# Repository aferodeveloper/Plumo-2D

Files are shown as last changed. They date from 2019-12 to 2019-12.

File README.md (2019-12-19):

# Plumo-2D Feather/FeatherWing compatible Development Board for the Afero Platform

## INTRODUCTION

Plumo-2D is a development board for the Afero ASR-2D Secure WiFi/BLE radio architecture based on the ESP32 WiFi/BLE chipset.  Plumo-2D is compatible with Adafruit Feather/FeatherWing form factor boards.

This reference design is meant for customers to use for product prototyping and as a starting point for their own designs.  The Plumo-2D uses the Espressif ESP32-WROOM-32D module + the Afero Hardware Security Module.  Use of the pre-certified Espressif ESP32-WROOM-32D module gives the board FCC/IC, TELEC, and other certifications.

For more information, please see the Afero developer site: https://developer.afero.io

## Design Information
The Plumo-2D design was built using Altium.  The entire Altium project, including scripts that generate the output files, is included.

## Manifest (abridged)
 * **Plumo-2D.PrjPcb** is the toplevel Altium project file.
 * **Plumo-2D.SchDoc** is the Altium schematic file.
 * **Plumo-2D.PcbDoc** is the Altium layout file.
 * **Plumo-2D.IntLib** is an integrated Altium part library for the design.
 * **AssyDrawing.PCBDwf** and **FabDrawing.PCBDwf** are drawing templates for the Assembly and Fabrication drawings.
 * **documentation.OutJob** and **gerbers.OutJob** are the "scripts" for Altium that you can use to generate all of the needed output files (pdf files, gerbers, pick and place info, et cetera).
 * **Plumo-2D.pdf** pdf of the schematics, isometric view of the board, fab and assembly drawings; autogenerated.
 * **gerbers** is the directory where the Gerber output files and ODB++ files are located.  These are the files that one would use when you release the board to fab and assembly; autogenerated.
 * **gerbers/Bill of Materials-Plumo-2D.csv** is the Bill of Materials for the debug version of the board; autogenerated.
 * **LICENSE.txt** Apache 2.0 license governing the use of this design.
 * **NOTICE** Copyright information.
 * **README.md** This file.

Please note that the Afero Secure Radio firmware stack and hardware security modules used in the design are not publicly available.  Please contact Afero about licensing these items.

## CONTRIBUTORS
Original design by Afero, Inc.

Copyright 2018, 2019 Afero, Inc.

Licensed under the Apache 2.0 license; check LICENSE.txt for more information.  All text above must be included in any redistribution.

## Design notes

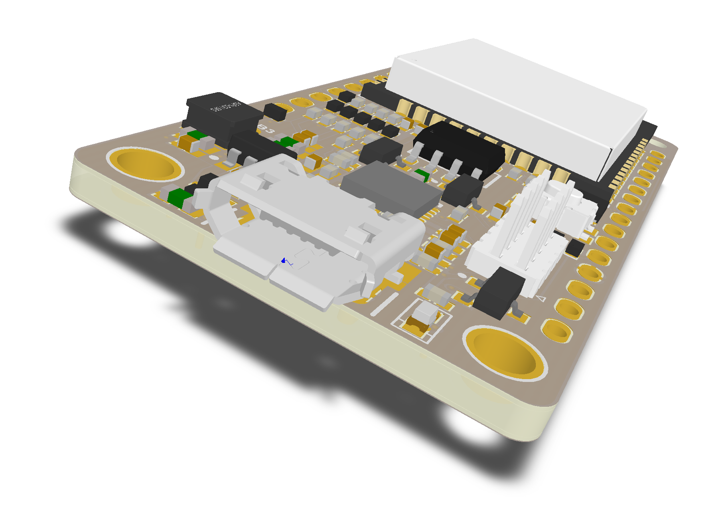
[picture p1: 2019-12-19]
Plumo2D_Iso-view.png

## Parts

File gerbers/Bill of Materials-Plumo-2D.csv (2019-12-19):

item_number | Comment | Quantity | Designator | Description | Manufacturer | Manufacturer Part Number
E-CAP-00090-00 | 100nF | 7 | C1, C3, C10, C11, C13, C15, C17 | Capacitor 100nF X5R 50V 10% 0402 | Murata | GRM155R61H104KE19D
E-CAP-00110-00 | 18pF | 2 | C2, C4 | Capacitor, 18pF, 50V, 1%, C0G | Murata | GJM1555C1H180FB01D
E-CAP-00020-00 | 1uF | 5 | C5, C12, C14, C16, C20 | Capacitor 1uF X5R 6.3V 20% 0402 | SEM | CL05A105KQ5NNNC
E-CAP-00100-00 | 10uF | 2 | C6, C7 | Capacitor 10uF X5R 16V 20% 0603 | Murata | GRM188R61C106MA73D
E-CAP-00107-00 | 20pF | 1 | C8 | Capacitor 20pF C0G 50V 1% 0402 | Murata | GJM1555C1H200FB01D
E-CAP-00108-00 | 2.2uF | 1 | C9 | Capacitor 2.2uF X5R 25V 10% 0603 | Murata | GRM188R61E225KA12D
E-CAP-00066-00 | 4.7uF | 2 | C18, C19 | Capacitor 4.7uF X5R 10V 10% 0603 | Taiyo Yuden | LMK107BJ475KA-T
E-DIO-00011-00 | SP3118-01ETG | 1 | D1 | Diode TVS | Littelfuse | SP3118-01ETG
E-DIO-00008-00 | TPD1E05U06 | 11 | D2, D3, D6, D7, D8, D9, D11, D12, D13, D14, D15 | Diode TVS | Texas Instruments | TPD1E05U06DPYR
E-LED-00012-00 | Orange | 1 | D4 | LED Orange 0603 | Vishay Lite-On | LTST-C190KAKT
E-DIO-00012-00 | NSR05T30XV2T5G | 1 | D10 | Diode Schottky 30V 0.5A SOD523 | On Semiconductor | NSR05T30XV2T5G
M-CON-00086-00 | HDR-1x12 | 1 | J2 | 0.1 header 12 positions" | Molex | 22032121
M-CON-00087-00 | HDR-1x16 | 1 | J3 | 0.1 header 16 positions" | Molex | 22032161
M-CON-00016-00 | HDR-2x5 | 1 | J4 | .050 Male Header 2x5 |  | GRPB052VWVN-RC
M-CON-00011-00 | 10103594-0001LF | 1 | J5 | Connector MICRO USB B | Amphenol FCI | 10103594-0001LF
E-IND-00043-00 | 10uH | 1 | L1 | Inductor 10uH 1.1A 0.22ohm 20% 3x3 | Abracon | ASPI-0315FS-100M
E-ICS-00097-00 | ESP32-WROOM-32D | 1 | MOD1 | Module WIFI BLE ESP32-D0WD 4MB | Espressif | ESP32-WROOM-32D
E-TRS-00003-00 | 2N7002 | 1 | Q2 | TR MOSFET N-CH 60V 115mA SOT23 | On Semiconductor | 2N7002
E-TRS-00002-00 | MMBT3904 | 2 | Q3, Q4 | TR NPN BJT 200mA 40V | On Semiconductor | MMBT3904LT1G
E-RES-00008-00 | 100 | 6 | R6, R17, R18, R19, R20, R22 | Resistor 100R 50V 5% 0402 | Panasonic | ERJ-2GEJ101X
E-RES-00039-00 | 4.7k | 3 | R7, R8, R31 | Resistor 4.7K 50V 5% 0402 | Panasonic | ERJ-2GEJ472X
E-RES-00012-00 | 100k | 2 | R9, R10 | Resistor 100K 50V 5% 0402 | Panasonic | ERJ-2GEJ104X
E-RES-00001-00 | 10k | 4 | R12, R13, R28, R29 | Resistor 10K 50V 5% 0402 | Vishay Dale | CRCW040210K0JNED
E-RES-00054-00 | 200K | 2 | R15, R21 | Resistor 200K 50V 1% 0402 | Panasonic | ERJ-2RKF2003X
E-RES-00093-00 | 680k | 1 | R16 | Resistor 680K 50V 5% 0402 | Panasonic | ERJ-2GEJ684X
E-RES-00006-00 | 0 | 1 | R23 | Resistor 0R 50V 1% 0402 | Yageo | RC0402FR-070RL
E-RES-00002-00 | 1k | 3 | R25, R26, R27 | Resistor 1K 50V 5% 0402 | Panasonic | ERJ-2GEJ102X
E-SWI-00022 | KMR231NGLFS | 1 | S1 | SMD Tact Switch | ITT C&K | KMR231NGLFS
E-ICS-00099-00 | IPS6404L-SQ | 1 | U1 | Memory SPI/QPI PSRAM 8MB SOIC8 150mil | IPUS | IPS6404L-SQ-SPN
E-ICS-00072-00 | ATECC508A | 1 | U2 | Afero Custom CryptoAuthentication Device | Microchip / Atmel | ATECC508A-MAHKN-T
E-ICS-00096-00 | XC9264B755MR | 1 | U3 | Voltage Regulator 0.5A 500KHz Buck | Torex | XC9264B755MR
E-ICS-00098-00 | CP2104 | 1 | U4 | USB to UART Bridge | SiLabs | CP2104-F03-GM
E-XTL-00012-00 | 32.768KHz | 1 | X1 | Crystal, 32.768kHz ±20ppm | Abracon | ABS06-32.768KHZ-T

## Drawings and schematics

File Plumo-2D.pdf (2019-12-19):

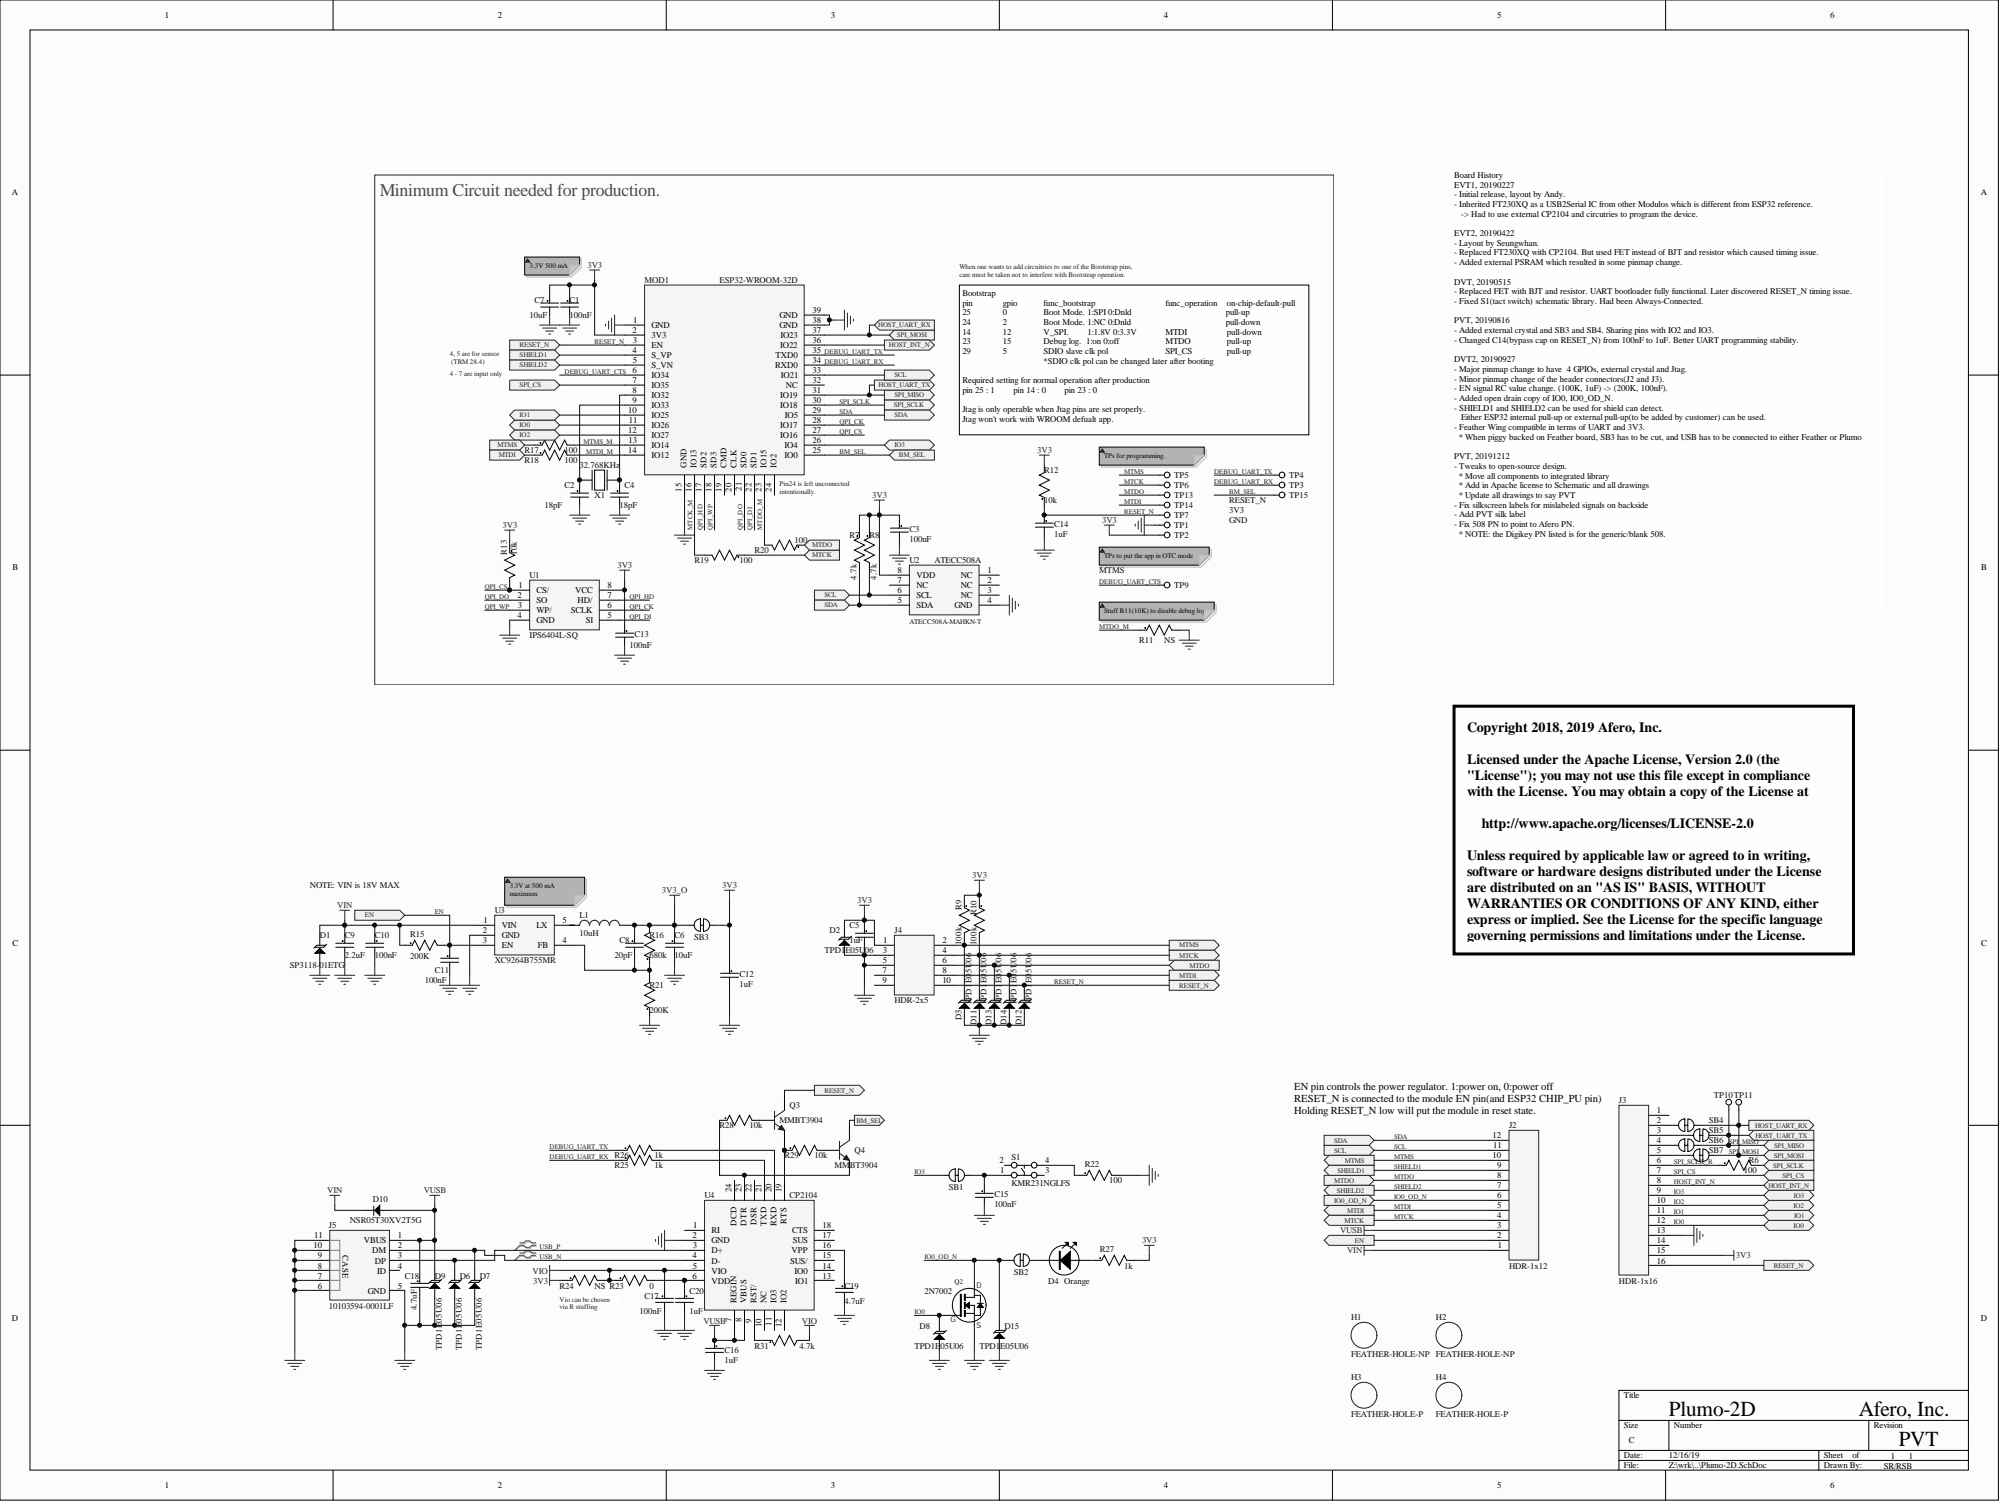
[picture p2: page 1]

Board History
EVT1, 20190227
- Initial release, layout by Andy.
- Inherited FT230XQ as a USB2Serial IC from other Modulos which is different from ESP32 reference.
-> Had to use external CP2104 and circutries to program the device.

Minimum Circuit needed for production.

EVT2, 20190422
- Layout by Seungwhan.
- Replaced FT230XQ with CP2104. But used FET instead of BJT and resistor which caused timing issue.
- Added external PSRAM which resulted in some pinmap change.

When one wants to add circuitries to one of the Bootstrap pins,
care must be taken not to interfere with Bootstrap operation.

DVT, 20190515
- Replaced FET with BJT and resistor. UART bootloader fully functional. Later discovered RESET_N timing issue.
- Fixed S1(tact switch) schematic library. Had been Always-Connected.

PVT, 20190816
- Added external crystal and SB3 and SB4. Sharing pins with IO2 and IO3.
- Changed C14(bypass cap on RESET_N) from 100nF to 1uF. Better UART programming stability.

*SDIO clk pol can be changed later after booting

DVT2, 20190927
- Major pinmap change to have 4 GPIOs, external crystal and Jtag.
- Minor pinmap change of the header connectors(J2 and J3).
- EN signal RC value change. (100K, 1uF) -> (200K, 100nF).
- Added open drain copy of IO0, IO0_OD_N.
- SHIELD1 and SHIELD2 can be used for shield can detect.
Either ESP32 internal pull-up or external pull-up(to be added by customer) can be used.
- Feather Wing compatible in terms of UART and 3V3.
* When piggy backed on Feather board, SB3 has to be cut, and USB has to be connected to either Feather or Plumo

Required setting for normal operation after production

IO25 10
IO26 11
IO27 12 | QPI_CS

Jtag is only operable when Jtag pins are set properly.
Jtag won't work with WROOM defualt app.

MTMS_M | IO14 13 | BM_SEL
MTDI_M | IO12 14
32.768KHz

PVT, 20191212
- Tweaks to open-source design.
* Move all components to integrated library
* Add in Apache license to Schematic and all drawings
* Update all drawings to say PVT
- Fix silkscreen labels for mislabeled signals on backside
- Add PVT silk label
- Fix 508 PN to point to Afero PN.
* NOTE: the Digikey PN listed is for the generic/blank 508.

TPs to put the app in OTC mode
MTMS
DEBUG_UART_CTS

Stuff R11(10K) to disable debug log

Licensed under the Apache License, Version 2.0 (the
"License"); you may not use this file except in compliance
with the License. You may obtain a copy of the License at

http://www.apache.org/licenses/LICENSE-2.0

Unless required by applicable law or agreed to in writing,
software or hardware designs distributed under the License
are distributed on an "AS IS" BASIS, WITHOUT
WARRANTIES OR CONDITIONS OF ANY KIND, either
express or implied. See the License for the specific language
governing permissions and limitations under the License.

NOTE: VIN is 18V MAX

EN pin controls the power regulator. 1:power on, 0:power off
RESET_N is connected to the module EN pin(and ESP32 CHIP_PU pin)
Holding RESET_N low will put the module in reset state.

Vio can be chosen
via R stuffing

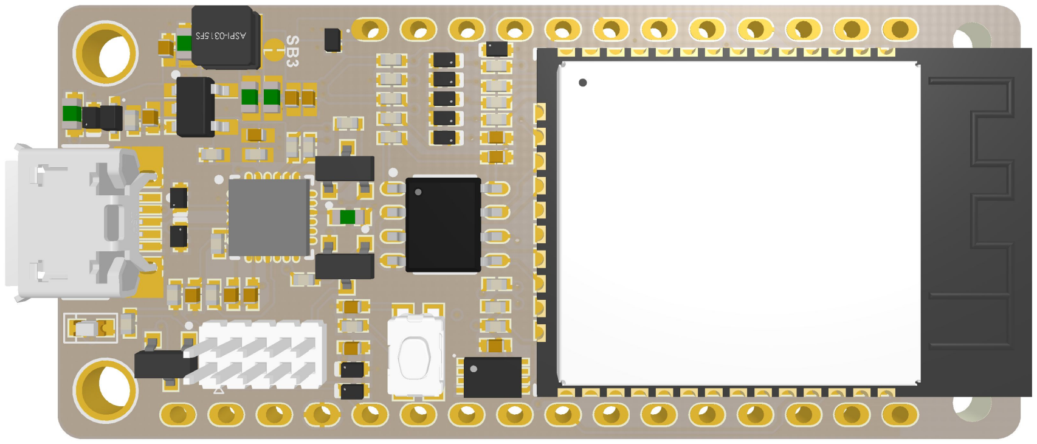
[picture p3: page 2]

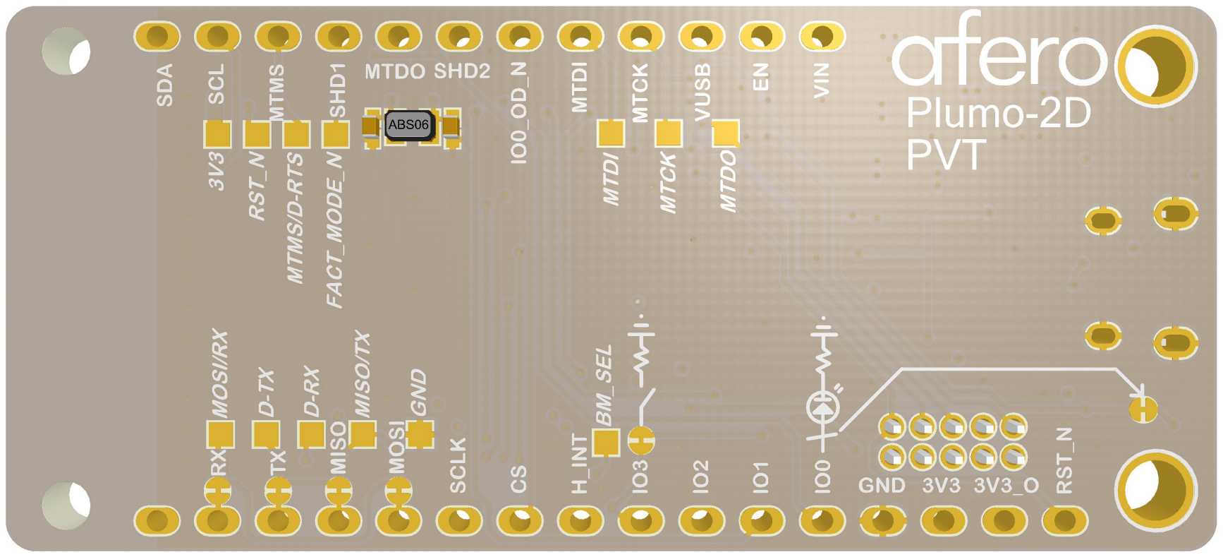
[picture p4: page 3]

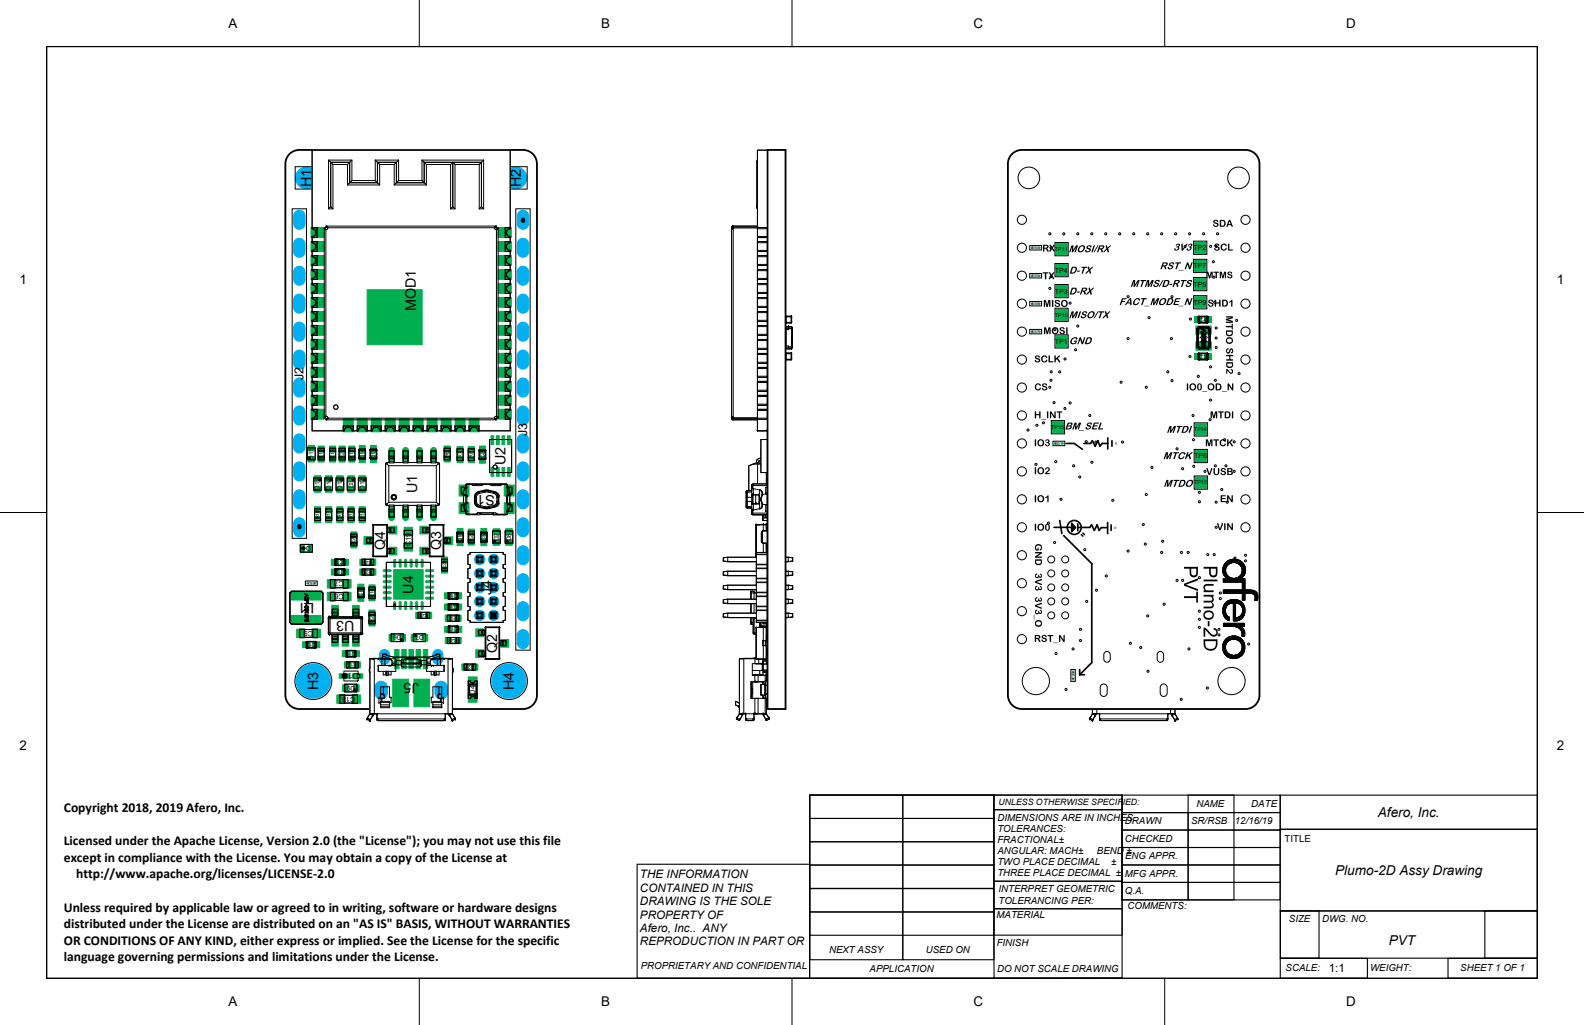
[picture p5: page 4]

UNLESS OTHERWISE SPECIFIED:
DIMENSIONS ARE IN INCHES
TOLERANCES:
FRACTIONAL±
TWO PLACE DECIMAL ±
THREE PLACE DECIMAL ±
INTERPRET GEOMETRIC
TOLERANCING PER:
MATERIAL

Licensed under the Apache License, Version 2.0 (the "License"); you may not use this file
except in compliance with the License. You may obtain a copy of the License at
http://www.apache.org/licenses/LICENSE-2.0

THE INFORMATION
CONTAINED IN THIS
DRAWING IS THE SOLE
PROPERTY OF
Afero, Inc.. ANY
REPRODUCTION IN PART OR

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

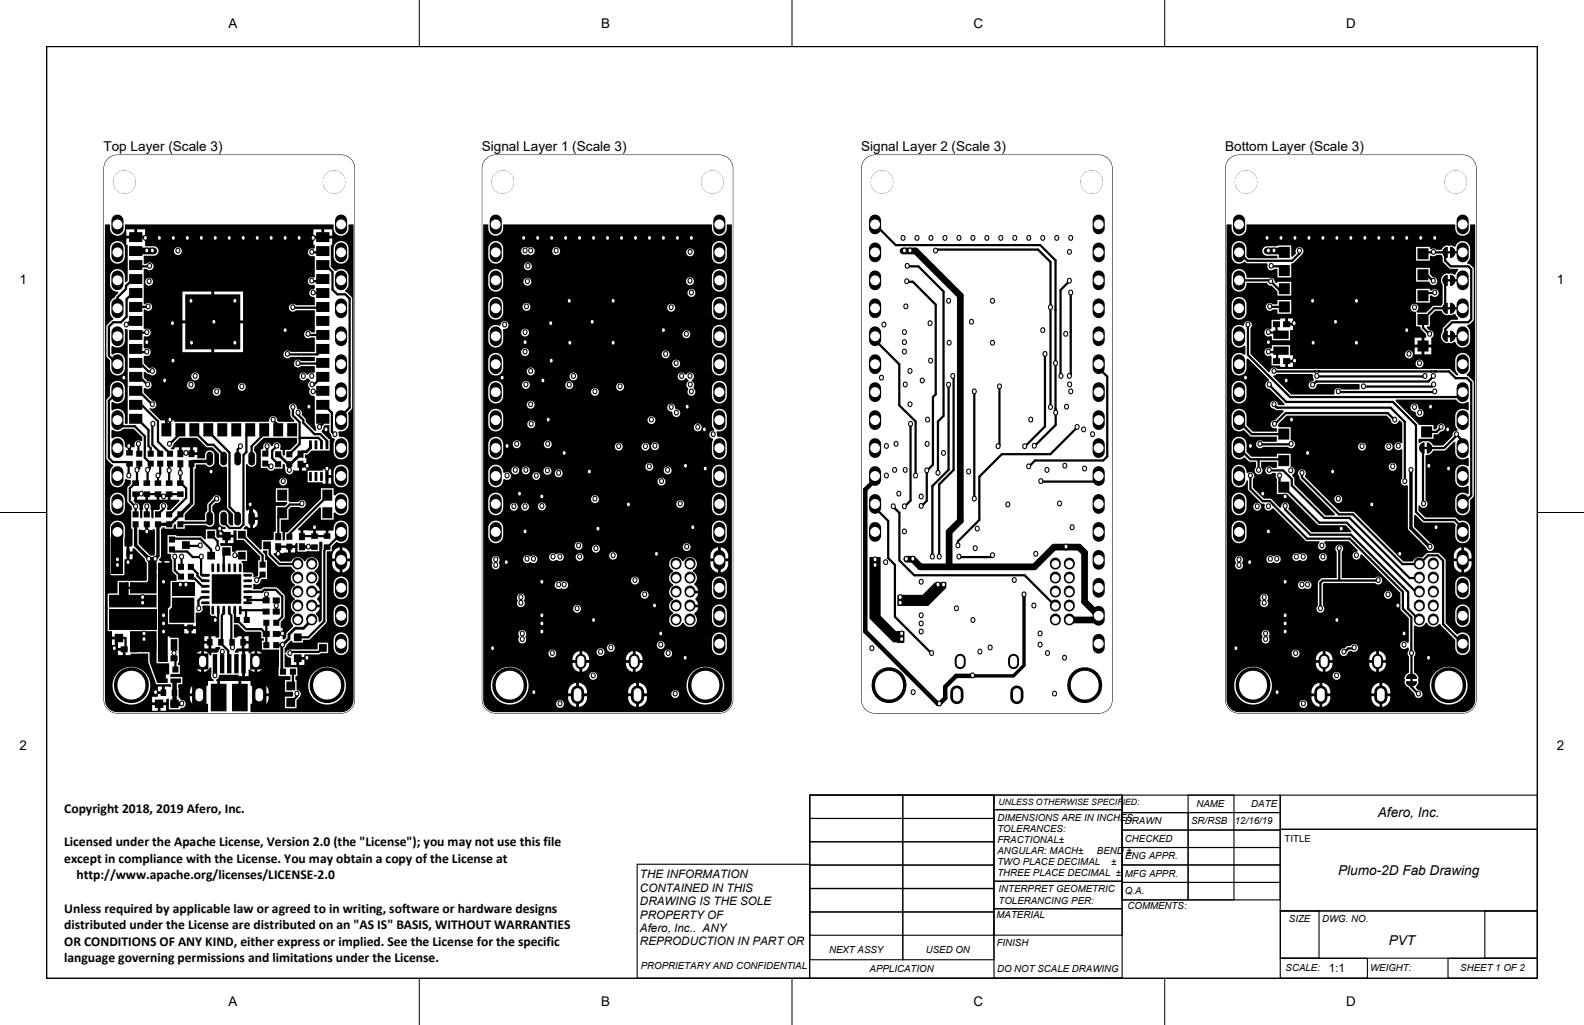
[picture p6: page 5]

UNLESS OTHERWISE SPECIFIED: | | NAME | DATE | Afero, Inc.
DIMENSIONS ARE IN INCHES TOLERANCES: FRACTIONAL± ANGULAR: MACH± BEND ± TWO PLACE DECIMAL ± THREE PLACE DECIMAL ± | DRAWN | SR/RSB | 12/16/19

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

CHECKED | | | TITLE Plumo-2D Fab Drawing
ENG APPR.
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
